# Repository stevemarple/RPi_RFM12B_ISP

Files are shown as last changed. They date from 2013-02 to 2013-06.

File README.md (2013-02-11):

# RPi_RFM12B_ISP

RFM12B and Atmel ISP programmer shield for Raspberry Pi

## Avrdude

Use the patched version of avrdude from http://project-downloads.drogon.net/files/. I suggest copying the
.avrduderc file from the avrdude directory in this repository to your home directory. It will create create 
the correct definitions for two new programmers, gpio0 for the onboard microcontroller and gpio1 for programming
other microcontrollers.

## Using the Arduino IDE

If you do not have a <code>hardware</code> directory inside your Arduino <code>sketchbook</code> folder
then create one. Copy the raspi directory and its entire contents to the hardware directory. Restart the 
Arduino IDE. You should now have two new board options, <code>ATmega328 @ 8MHz on RasPi</code> and 
<code>ATmega328P @ 8MHz on RasPi</code>. Select the one which matches the microcontroller. There are also two new
programmers; <code>Raspberry Pi GPIO (onboard)</code> and <code>Raspberry Pi GPIO (external ISP)</code>. 
The onboard one will be used automatically to upload new sketches to the RFM12B/ISP shield. The external ISP
programmer can be selected to program other microcontrollers from within the Arduino IDE.

## License

Unless indicated otherwise hardware is released under the Creative
Commons Attribution-ShareAlike 3.0 Unported (CC BY-SA 3.0)
http://creativecommons.org/licenses/by-sa/3.0/

Unless indicated otherwise software is released under the GNU Lesser
General Public License, version 2.1.
http://www.gnu.org/licenses/lgpl-2.1.html

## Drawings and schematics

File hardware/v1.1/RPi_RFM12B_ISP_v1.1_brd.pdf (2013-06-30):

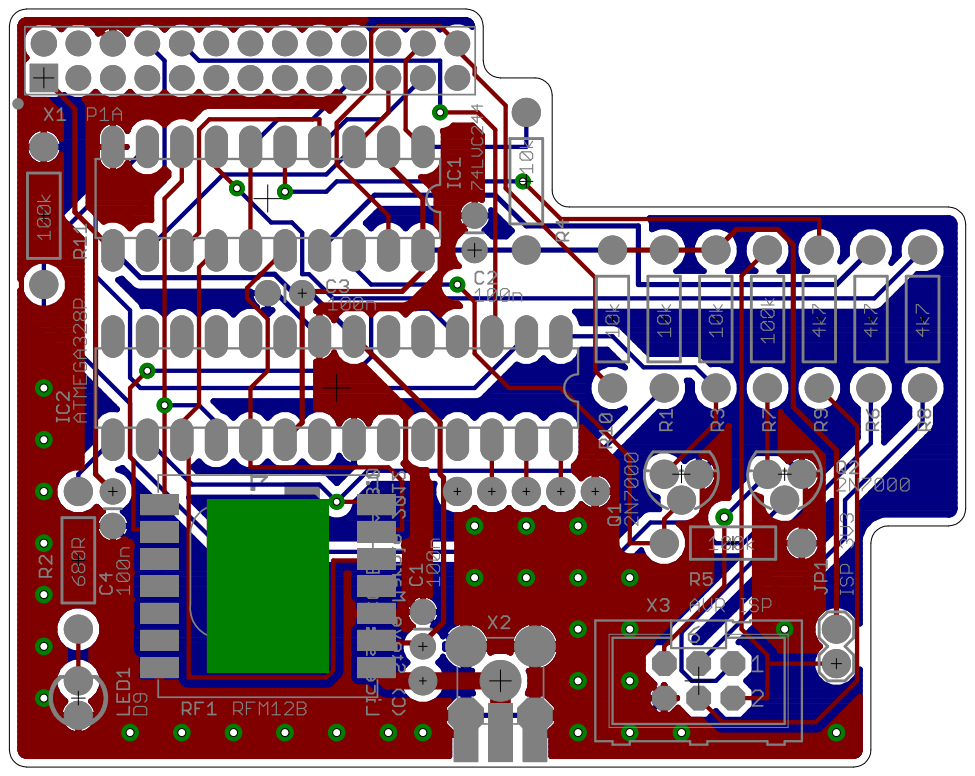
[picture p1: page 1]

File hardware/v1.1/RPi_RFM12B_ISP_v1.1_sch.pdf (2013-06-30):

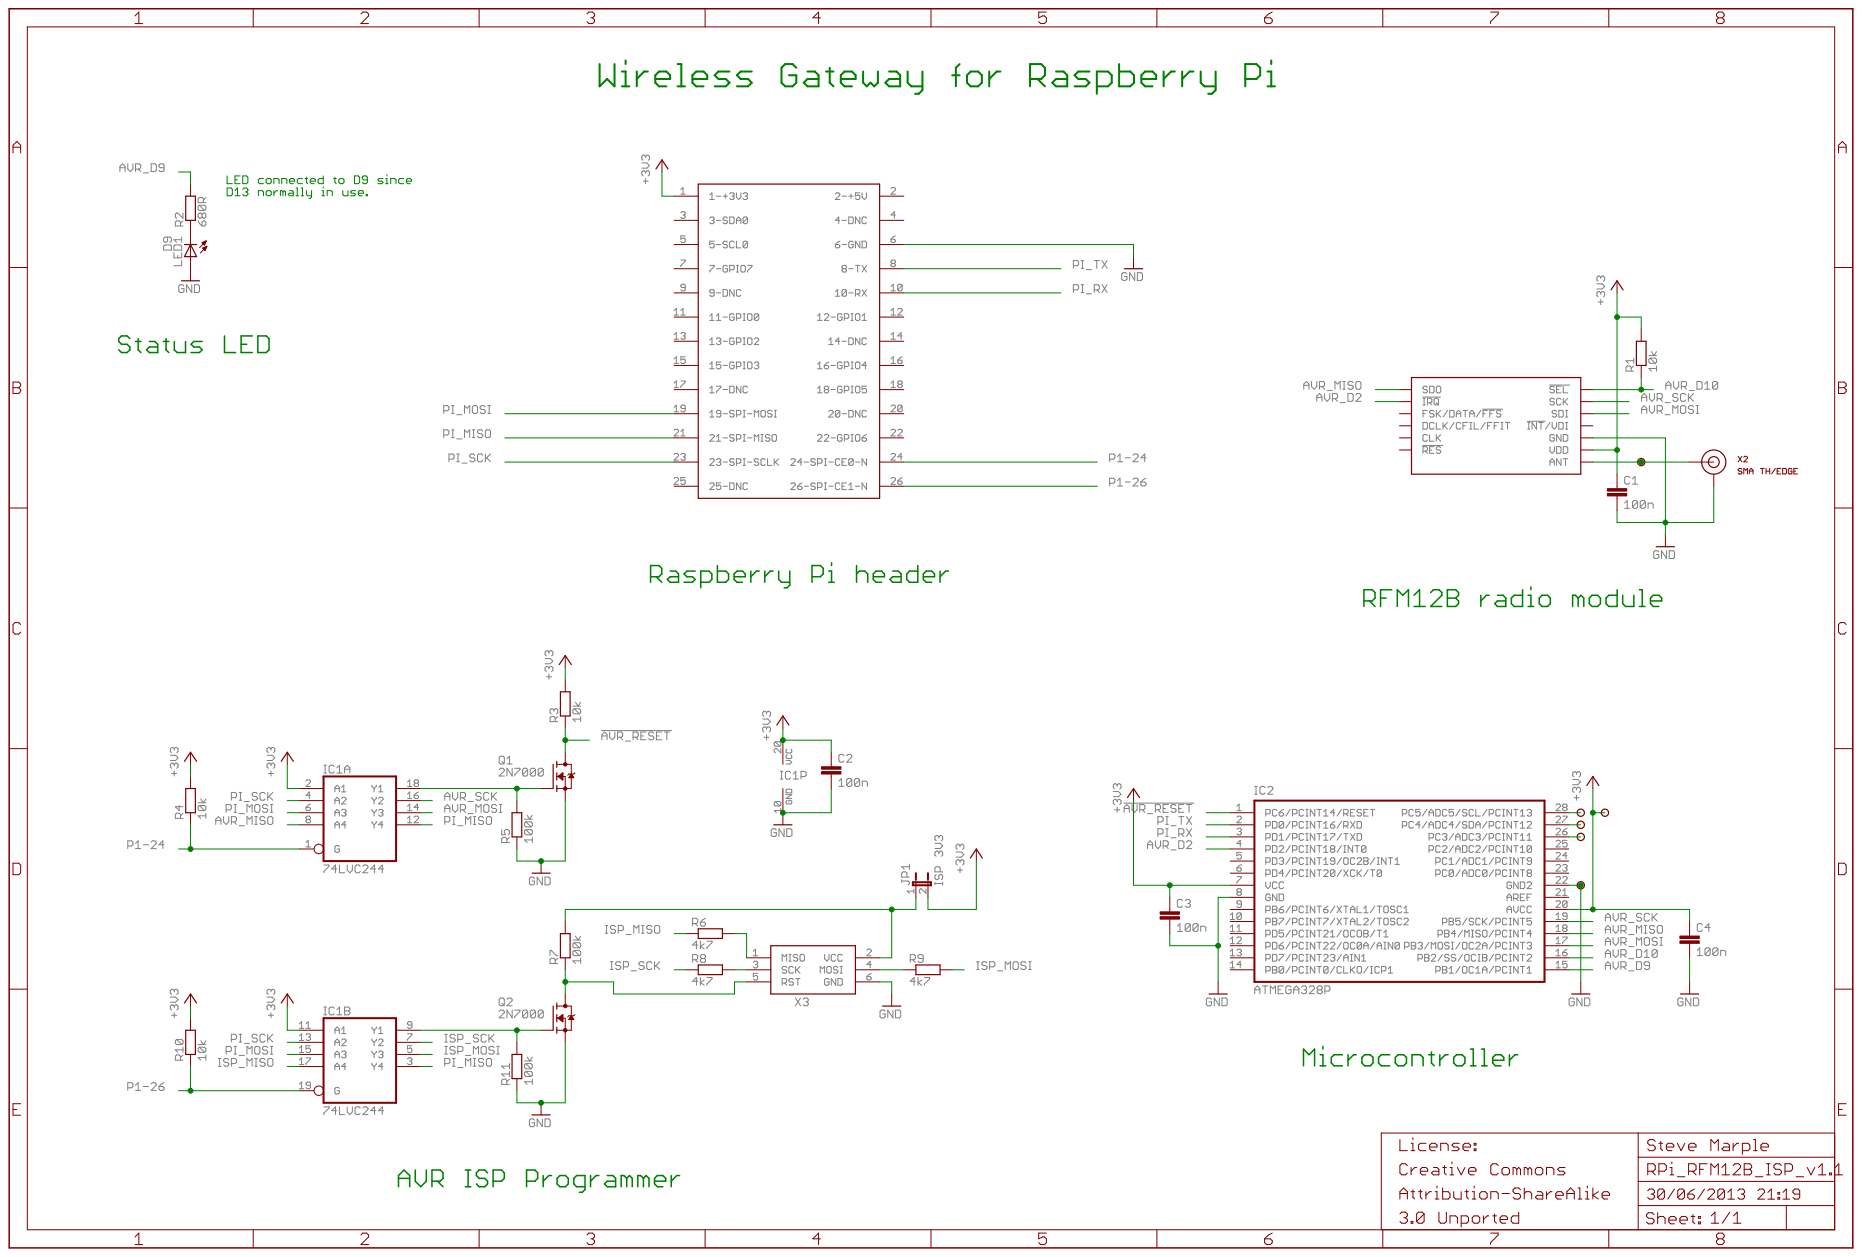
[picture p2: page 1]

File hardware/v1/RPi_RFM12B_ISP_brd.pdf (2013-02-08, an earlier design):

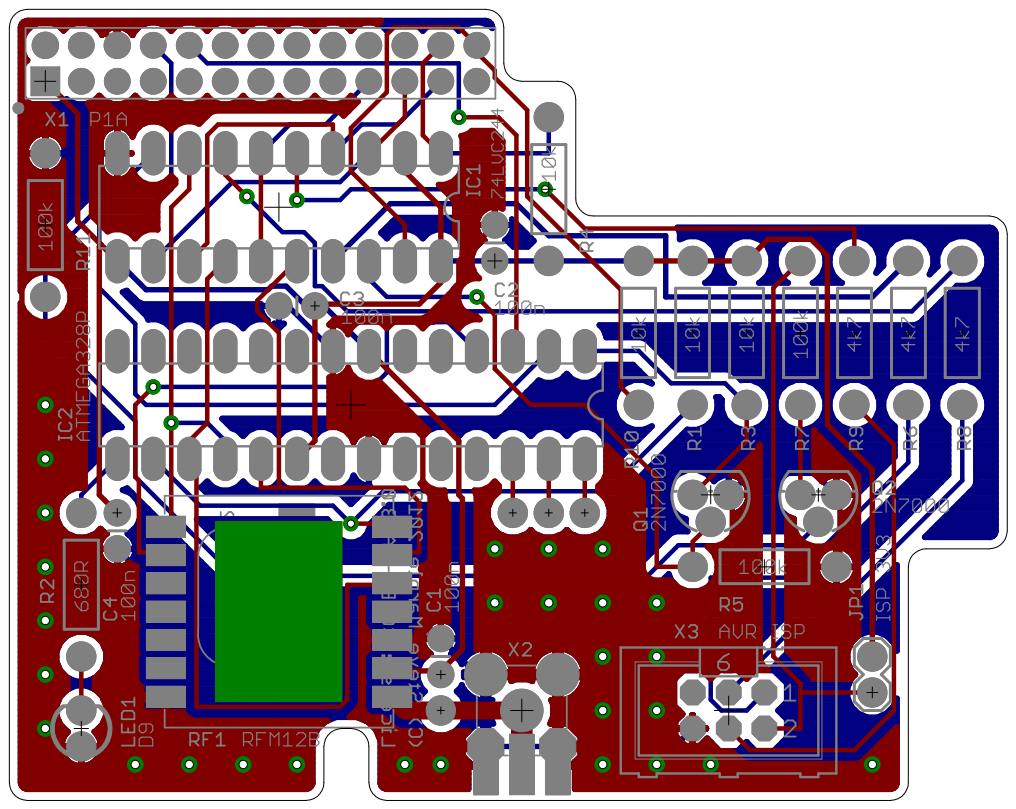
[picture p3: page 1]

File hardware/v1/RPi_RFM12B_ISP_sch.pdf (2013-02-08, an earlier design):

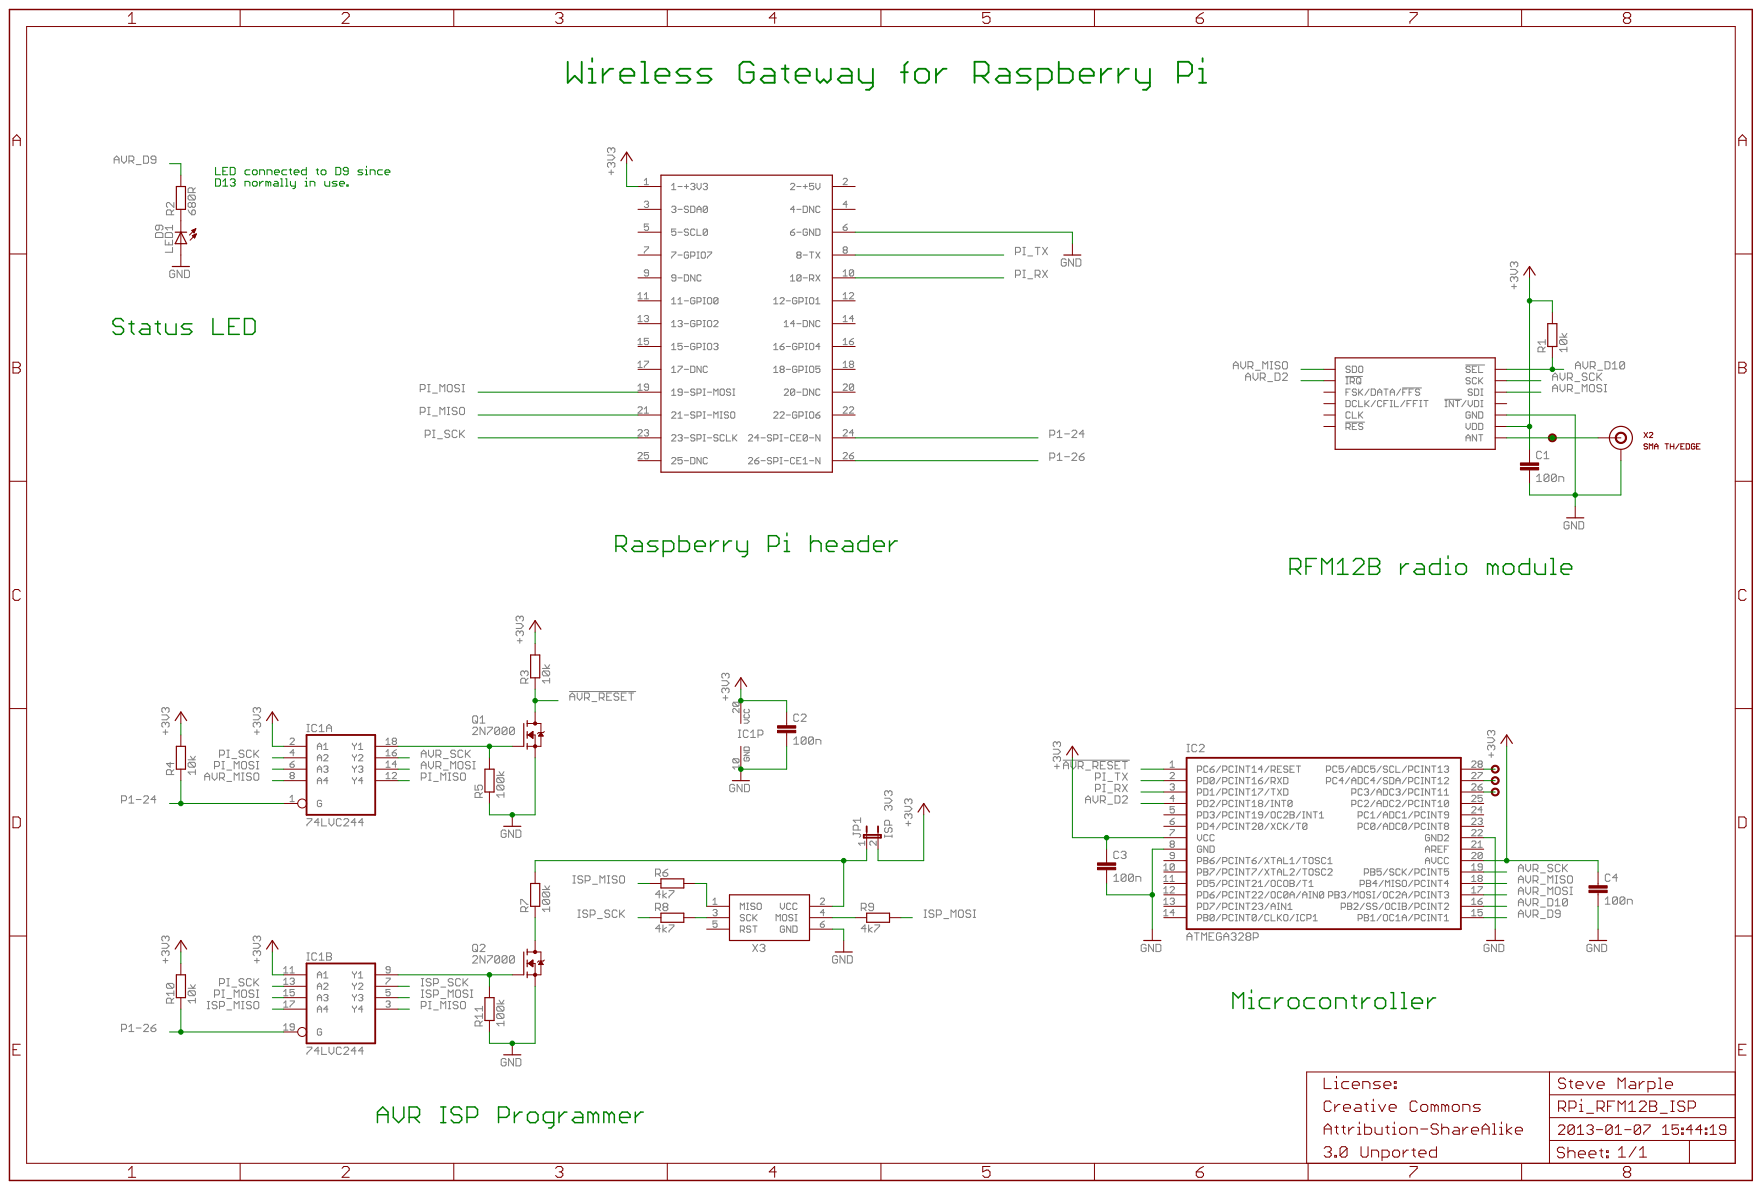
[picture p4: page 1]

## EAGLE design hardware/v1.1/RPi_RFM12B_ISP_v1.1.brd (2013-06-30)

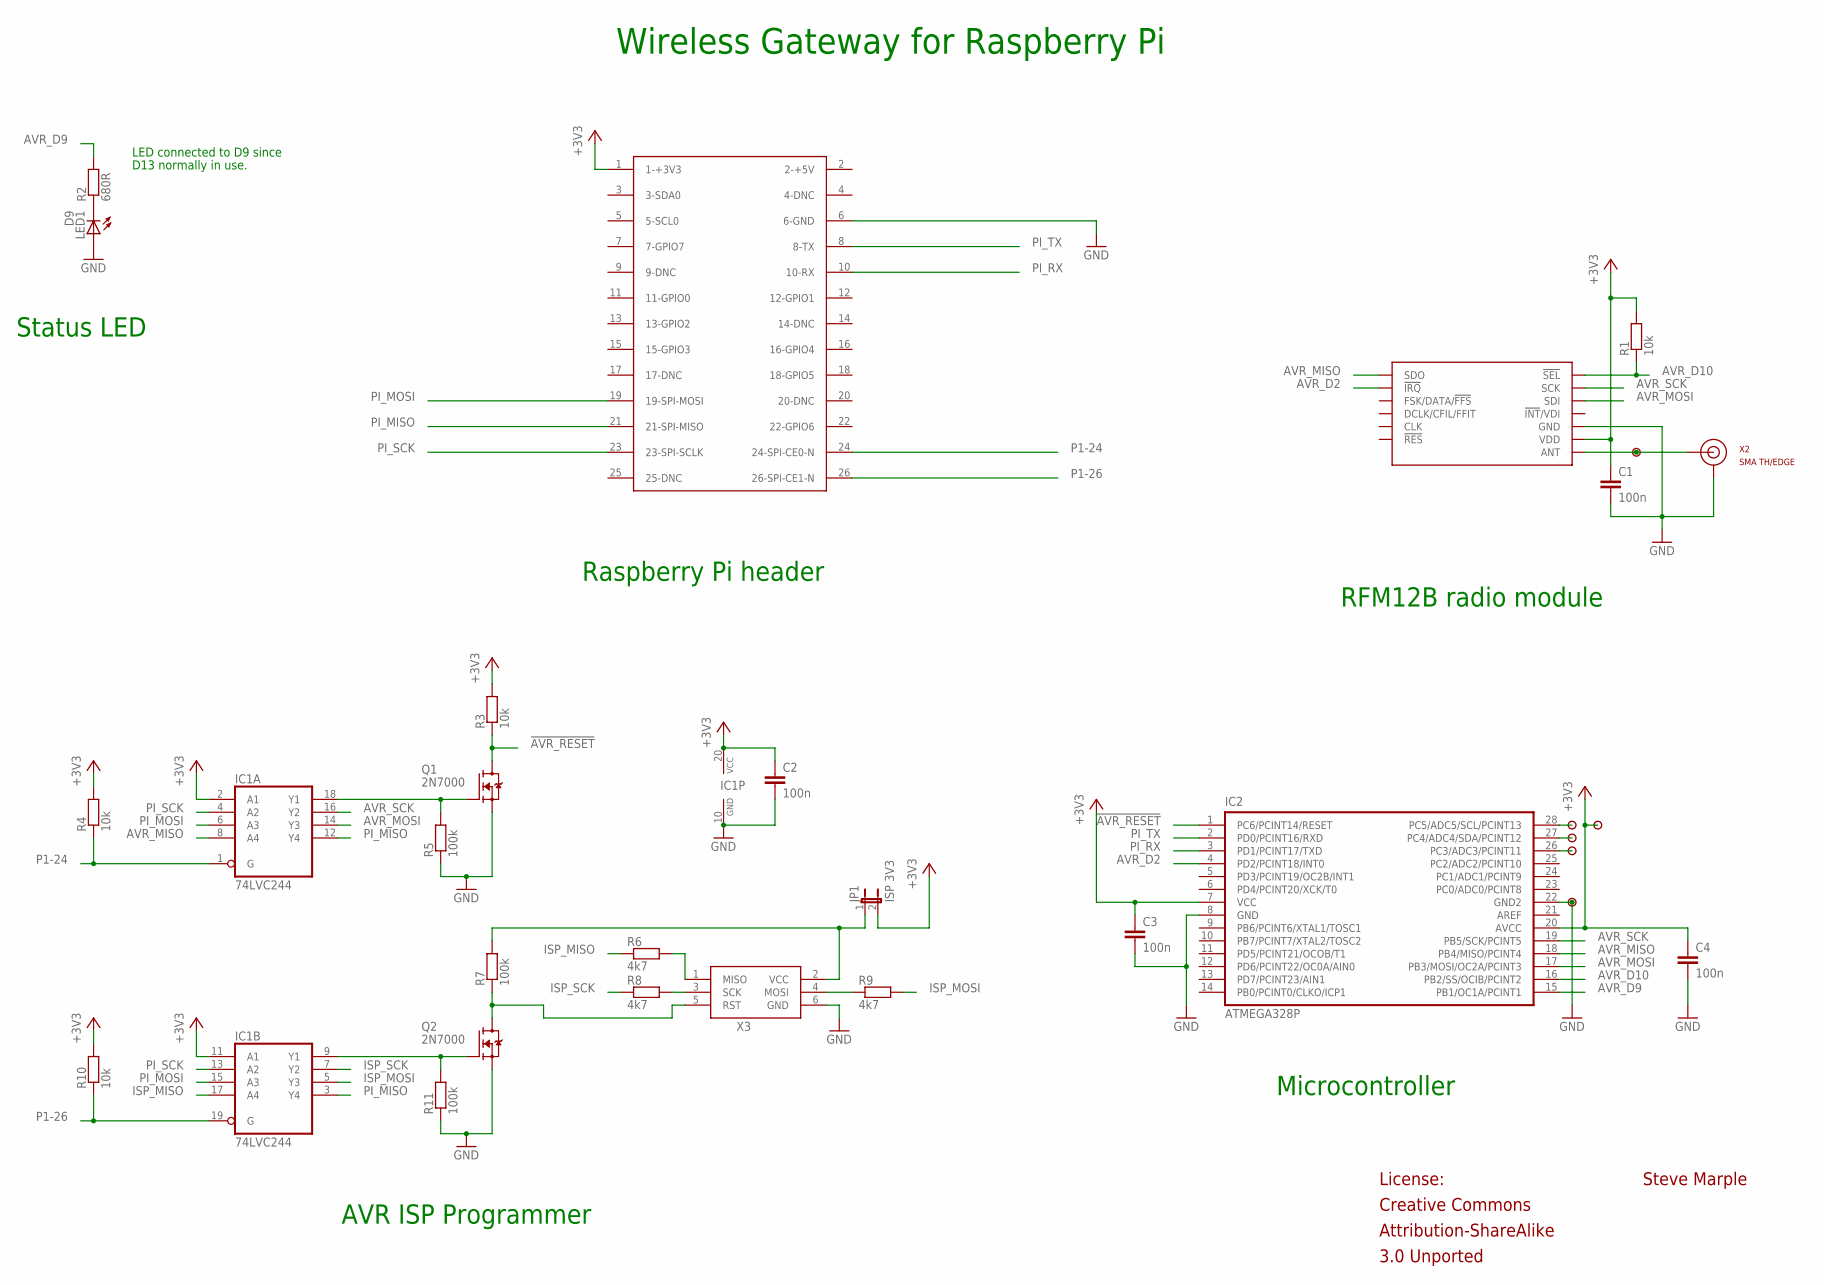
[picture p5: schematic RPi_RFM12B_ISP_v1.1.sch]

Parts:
AVR_A1, AVR_A2, AVR_A3, AVR_A4, AVR_A5: PAD
C1, C2, C3, C4: 100n; CAP-PTH-SMALL
IC1: 74LVC244; DIL20
IC2: ATMEGA328P; DIL28-N
JP1: ISP 3V3; 1X02
LED1: D9; LED3MM
Q1, Q2: 2N7000; TO-92
R1, R3, R4, R10: 10k; RES-AXIAL-0.4
R2: 680R; RES-AXIAL-0.4
R5, R7, R11: 100k; RES-AXIAL-0.4
R6, R8, R9: 4k7; RES-AXIAL-0.4
RF1: RFM12B
RFM12B_ANT: PAD
X1: P1A; RASPBERRY-PI-HEADER
X2: SMA TH/EDGE; SMA-THD-EDGE
X3: AVR ISP; CONN-HARTING-ML6

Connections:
!AVR_RESET: IC2.1 (PC6/PCINT14/RESET), Q1.3 (D), R3.P$1 (1)
+3V3: AVR_A5.1, C1.1, C2.1, C3.1, C4.1, IC1.2 (A1), IC1.11 (A1), IC1.20 (VCC), IC2.7 (VCC), IC2.20 (AVCC), JP1.2, R1.P$2 (2), R3.P$2 (2), R4.P$2 (2), R10.P$2 (2), RF1.VDD, X1.1 (1-+3V3)
AVR_D2: IC2.4 (PD2/PCINT18/INT0), RF1.!IRQ
AVR_D9: IC2.15 (PB1/OC1A/PCINT1), R2.P$2 (2)
AVR_D10: IC2.16 (PB2/SS/OCIB/PCINT2), R1.P$1 (1), RF1.!SEL
AVR_MISO: IC1.8 (A4), IC2.18 (PB4/MISO/PCINT4), RF1.SDO
AVR_MOSI: IC1.14 (Y3), IC2.17 (PB3/MOSI/OC2A/PCINT3), RF1.SDI
AVR_SCK: IC1.16 (Y2), IC2.19 (PB5/SCK/PCINT5), RF1.SCK
GND: AVR_A4.1, C1.2, C2.2, C3.2, C4.2, IC1.10 (GND), IC2.8 (GND), IC2.22 (GND2), LED1.A, Q1.1 (S), Q2.1 (S), R5.P$1 (1), R11.P$1 (1), RF1.GND@0 (GND), RF1.GND@1 (GND), X1.6 (6-GND), X2.GND@0 (GND), X2.GND@1 (GND), X2.GND@2 (GND), X2.GND@3 (GND), X2.GND@EDGE0 (GND), X2.GND@EDGE1 (GND), X2.GND@EDGE2 (GND), X2.GND@EDGE3 (GND), X3.6 (GND)
ISP_MISO: IC1.17 (A4), R6.P$1 (1)
ISP_MOSI: IC1.5 (Y3), R9.P$2 (2)
ISP_SCK: IC1.7 (Y2), R8.P$1 (1)
unnamed: RF1.ANT, RFM12B_ANT.1, X2.SIG (SIGNAL), X2.SIG@EDGE (SIGNAL)
unnamed: LED1.K (C), R2.P$1 (1)
unnamed: AVR_A1.1, IC2.28 (PC5/ADC5/SCL/PCINT13)
unnamed: AVR_A2.1, IC2.27 (PC4/ADC4/SDA/PCINT12)
unnamed: AVR_A3.1, IC2.26 (PC3/ADC3/PCINT11)
unnamed: IC1.18 (Y1), Q1.2 (G), R5.P$2 (2)
unnamed: R8.P$2 (2), X3.3 (SCK)
unnamed: R6.P$2 (2), X3.1 (MISO)
unnamed: IC1.9 (Y1), Q2.2 (G), R11.P$2 (2)
unnamed: Q2.3 (D), R7.P$1 (1), X3.5 (RST)
unnamed: JP1.1, R7.P$2 (2), X3.2 (VCC)
unnamed: R9.P$1 (1), X3.4 (MOSI)
P1-24: IC1.1 (G), R4.P$1 (1), X1.24 (24-SPI-CE0-N)
P1-26: IC1.19 (G), R10.P$1 (1), X1.26 (26-SPI-CE1-N)
PI_MISO: IC1.3 (Y4), IC1.12 (Y4), X1.21 (21-SPI-MISO)
PI_MOSI: IC1.6 (A3), IC1.15 (A3), X1.19 (19-SPI-MOSI)
PI_RX: IC2.3 (PD1/PCINT17/TXD), X1.10 (10-RX)
PI_SCK: IC1.4 (A2), IC1.13 (A2), X1.23 (23-SPI-SCLK)
PI_TX: IC2.2 (PD0/PCINT16/RXD), X1.8 (8-TX)

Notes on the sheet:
Raspberry Pi header
RFM12B radio module
Wireless Gateway for Raspberry Pi
AVR ISP Programmer
Steve Marple
Creative Commons
Attribution-ShareAlike
3.0 Unported
License:
Status LED
LED connected to D9 since
D13 normally in use.
Microcontroller

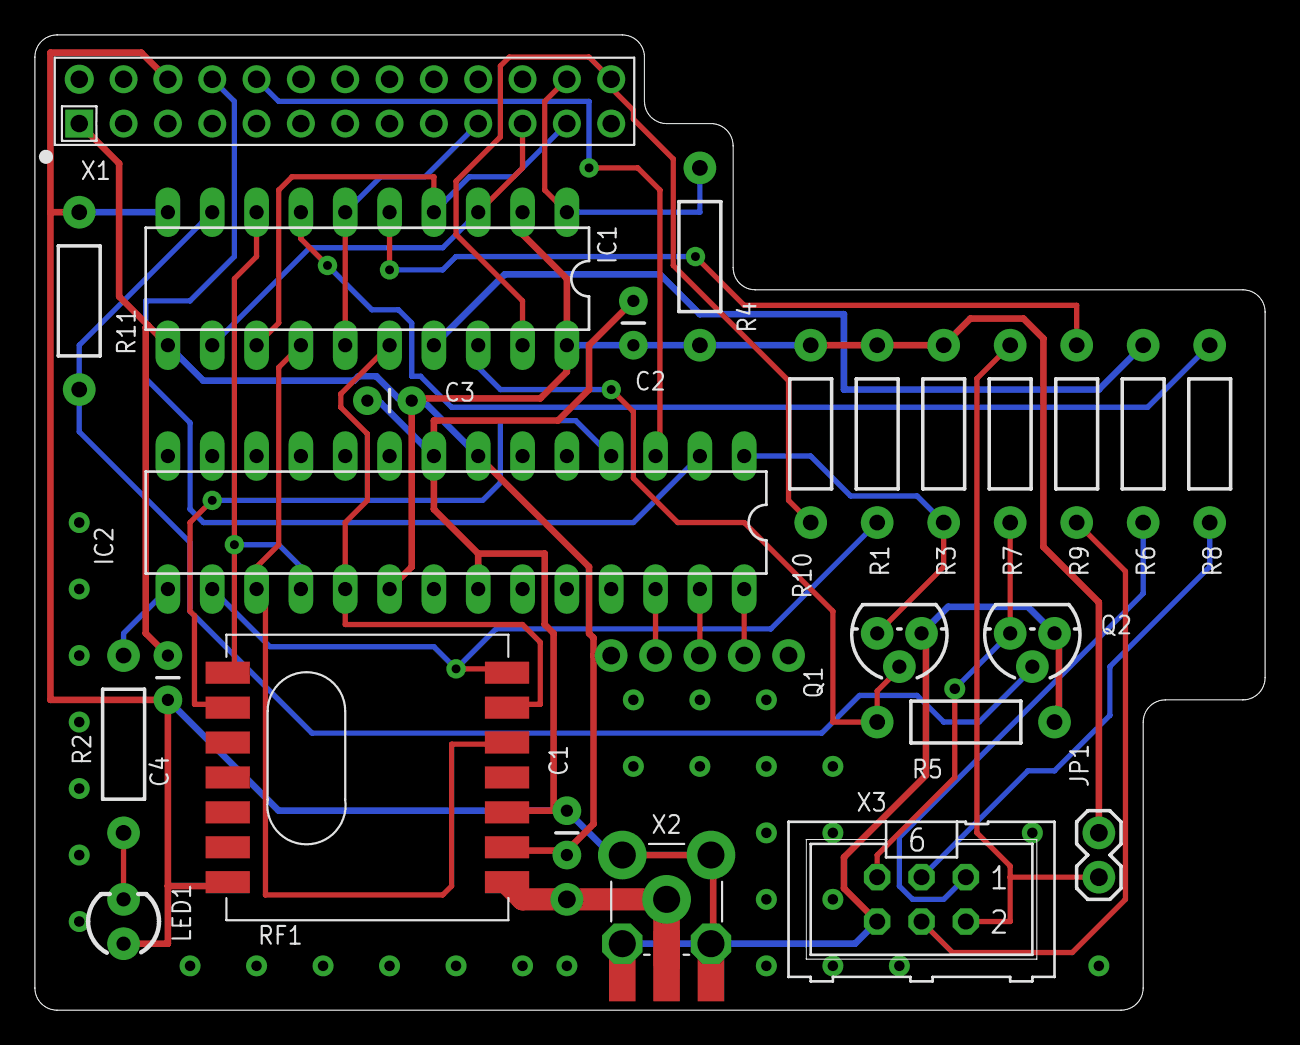
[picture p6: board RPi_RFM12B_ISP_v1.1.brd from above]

Board: 2 copper layers, 70.5 x 55.9 mm, 31 parts (0 on the bottom side), 31 nets.

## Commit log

2012-12-28 Adding schematic and board files for preliminary version.
    [RPi_RFM12B_ISP.brd, RPi_RFM12B_ISP.sch]
2013-02-08 Creating separate directory for hardware design files.
    [RPi_RFM12B_ISP.brd, RPi_RFM12B_ISP.sch]
2013-02-08 Adding Arduino IDE and avrdude files.
2013-02-08 Adding/updating to final Eagle PCB files.
    [RPi_RFM12B_ISP.brd, RPi_RFM12B_ISP.sch]
2013-02-08 Adding Gerber files.
    [RPi_RFM12B_ISP.GBL, RPi_RFM12B_ISP.GBO, RPi_RFM12B_ISP.GBS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]
2013-02-11 Setting brown-out detection (2.7V) in the fuses.
2013-02-15 Preliminary design for version 1.1.
    Adding missing /RESET connection for external ISP header. Removing cutout since board is too high for the Multicomp case. Adding +3.3V and ground pads.
    [RPi_RFM12B_ISP_v1.1.brd, RPi_RFM12B_ISP_v1.1.sch]
2013-06-30 Adding design rules and CAM files used for creation of Gerber files.
2013-06-30 Adding README file to describe current production status.

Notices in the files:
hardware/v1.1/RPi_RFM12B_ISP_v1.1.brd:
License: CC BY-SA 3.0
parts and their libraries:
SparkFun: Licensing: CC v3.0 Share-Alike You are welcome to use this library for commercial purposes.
